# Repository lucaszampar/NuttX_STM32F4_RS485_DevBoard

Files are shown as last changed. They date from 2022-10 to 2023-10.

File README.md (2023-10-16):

# NuttX_STM32F4_RS485_DevBoard

This is the first release of a development board using the STM32F401RCT6 as the main MCU.

### Features Implemented on the Board:
- Digital I2C Temperature Sensor (TMP75)
- 256KB I2C EEPROM
- On-board RS485 Transceiver
- Two Analog Input Stages with Amplifier Buffer
- Two Analog Output Stages with Amplifier Buffer
- MicroSD Connector supporting 1 or 4-bit bus
- Four User LEDs
- Four User Buttons
- USB for DFU (Device Firmware Update) and USB device functionality, as well as powering the board
- Onboard voltage regulator from 5V to 3.3V
- SWD Pins for use as STLink (Pin header) and TC2030-IDC 6-Pin Tag-Connect Plug-of-Nails™ Connector ([More Info](https://www.tag-connect.com/product/tc2030-idc-6-pin-tag-connect-plug-of-nails-spring-pin-cable-with-legs))
- Crystal for HS 8MHz
- Crystal for RTC 32.768KHz
- STL Case available

### 3D Board Render
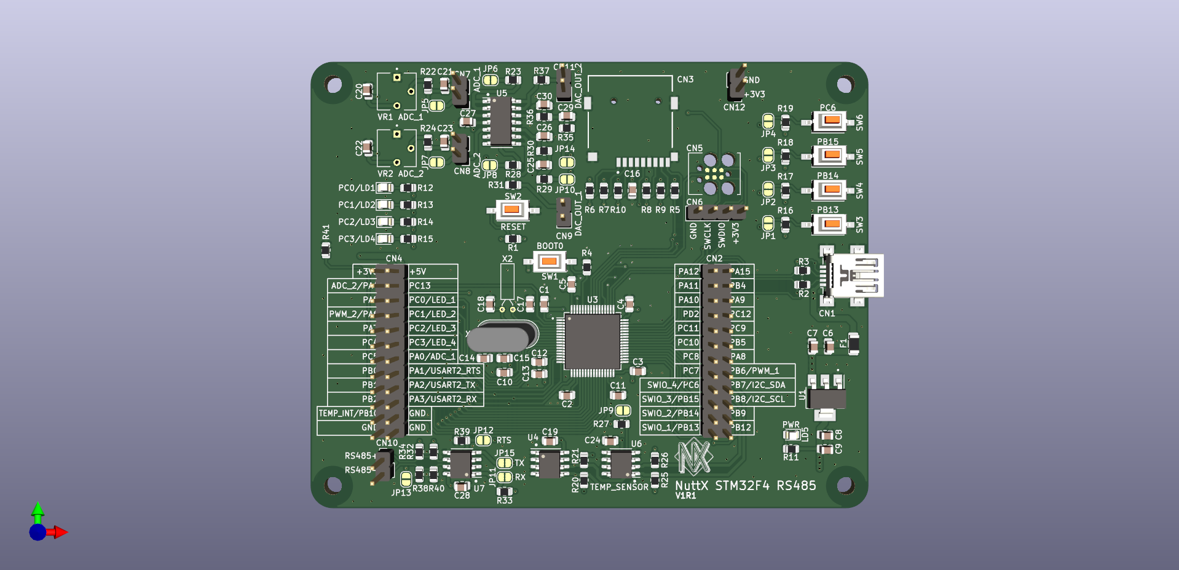
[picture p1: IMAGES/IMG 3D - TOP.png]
3D Board Render


### Case
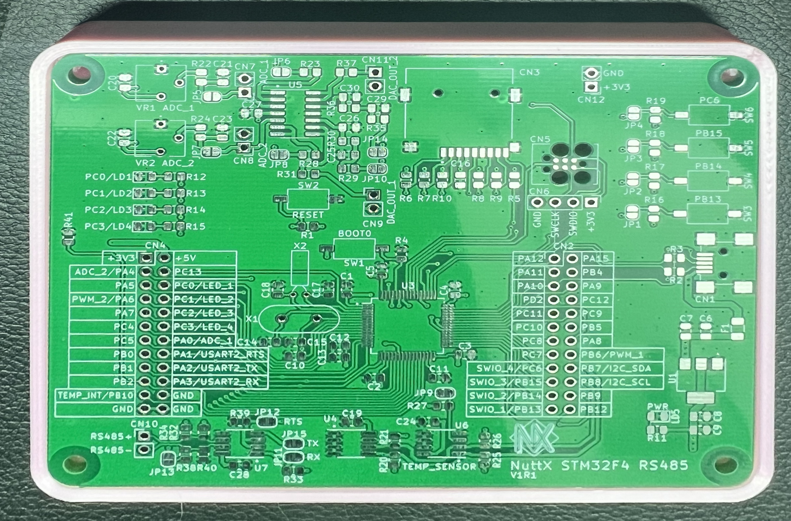
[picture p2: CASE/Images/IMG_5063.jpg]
Printed case with board


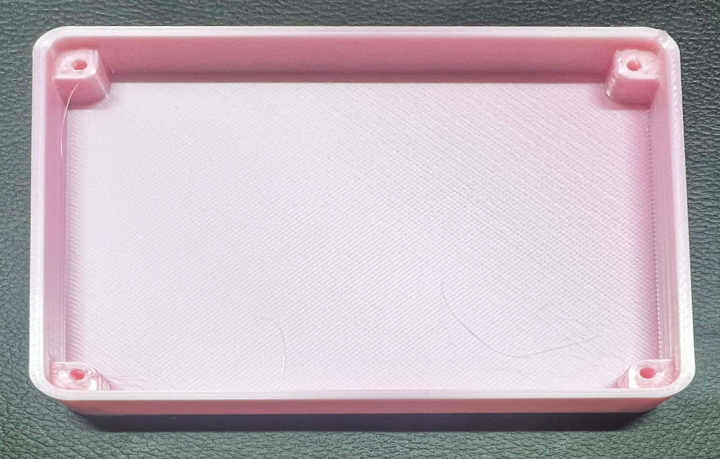
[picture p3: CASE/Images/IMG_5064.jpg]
Printed case without board


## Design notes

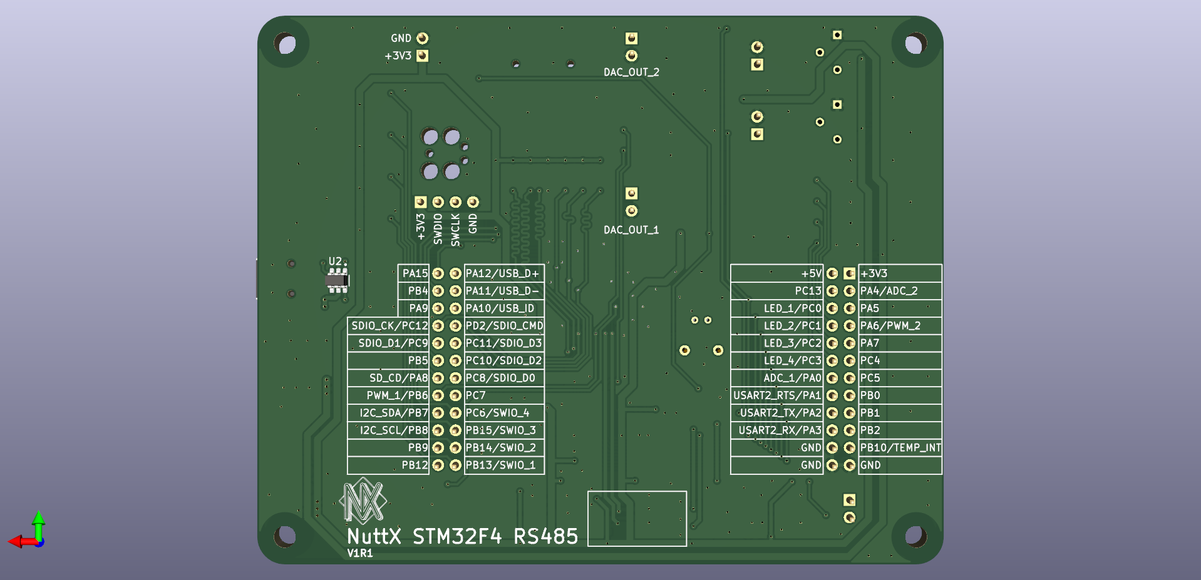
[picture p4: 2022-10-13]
IMAGES/IMG 3D - BOT.png

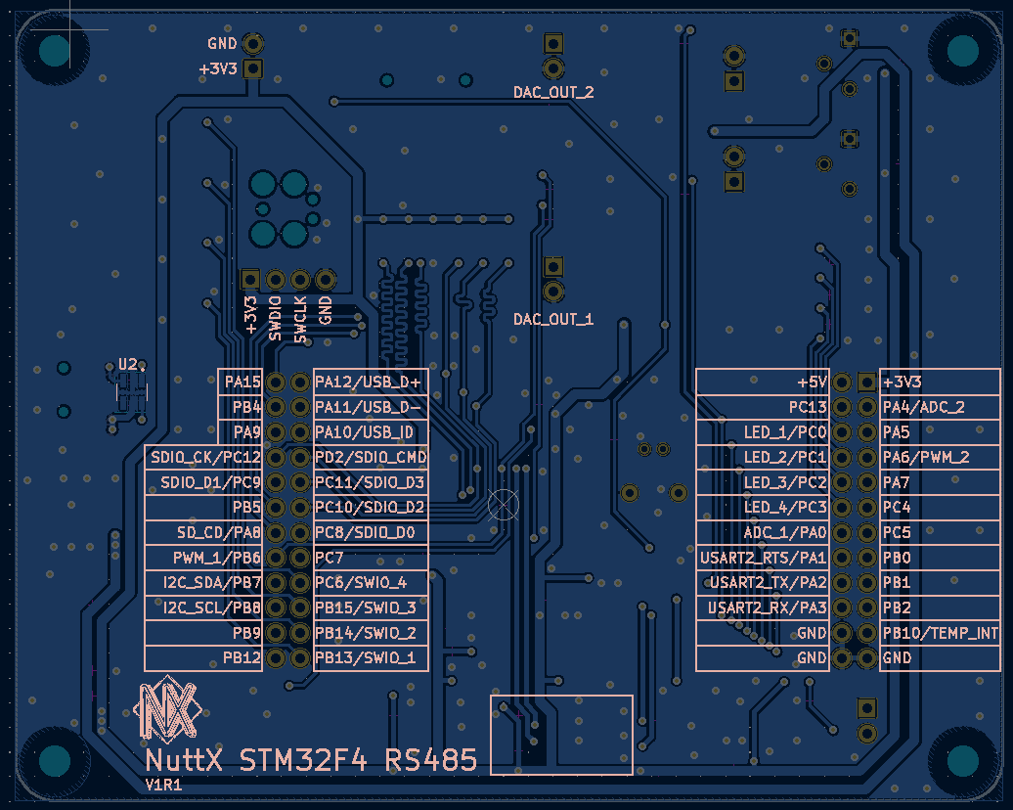
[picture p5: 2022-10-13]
IMAGES/IMG 2D - BOT.png

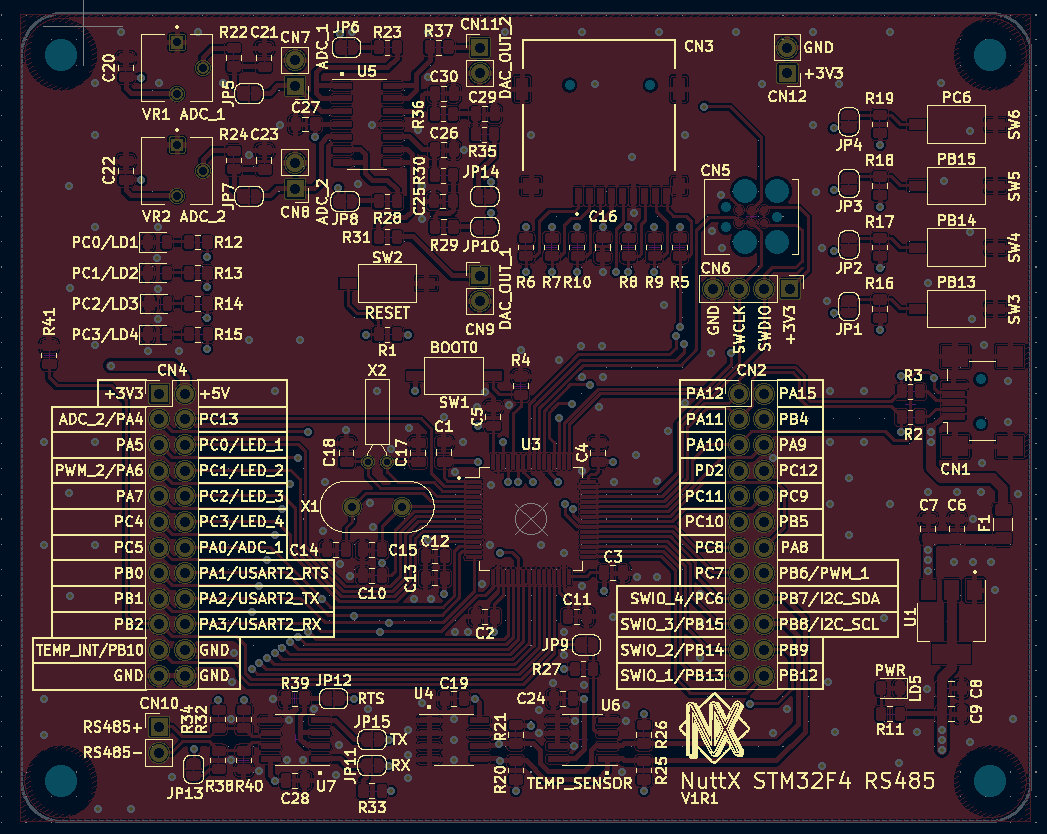
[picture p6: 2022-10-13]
IMAGES/IMG 2D - TOP.png

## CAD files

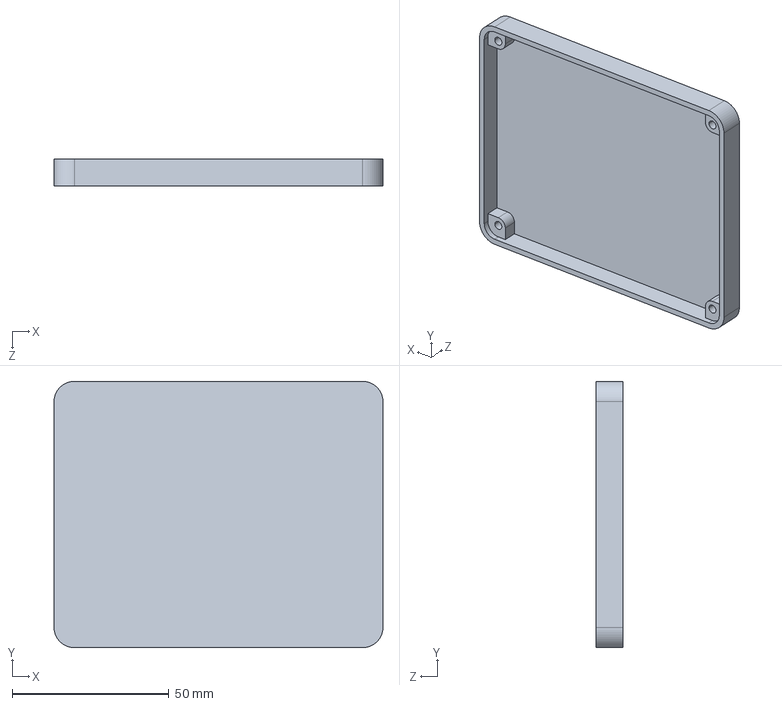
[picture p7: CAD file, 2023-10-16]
CASE/Files/Case.STEP
105.0 x 85.0 x 8.50 mm

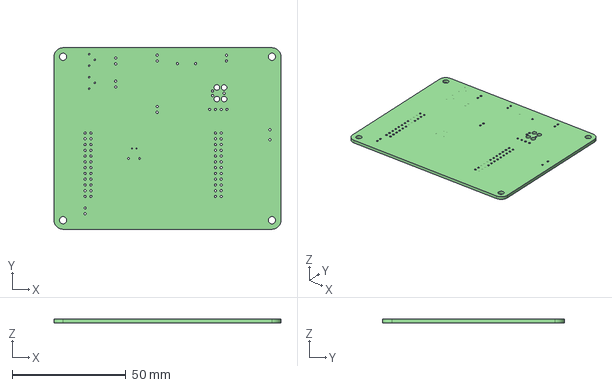
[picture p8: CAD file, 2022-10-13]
STEP/NuttX_STM32F4_RS485.step
100.0 x 80.0 x 1.60 mm

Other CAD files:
CASE/Files/Case.STL

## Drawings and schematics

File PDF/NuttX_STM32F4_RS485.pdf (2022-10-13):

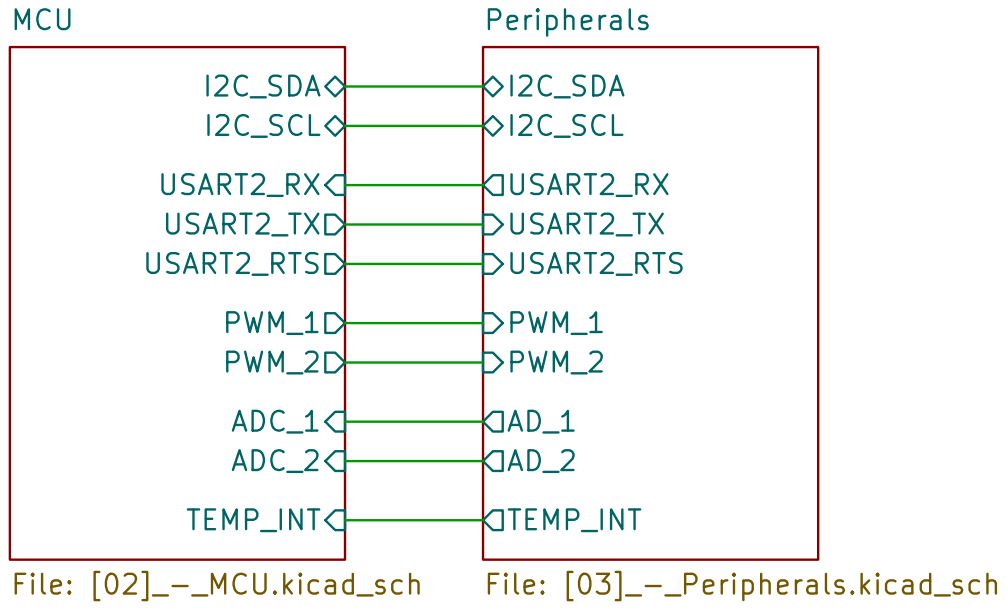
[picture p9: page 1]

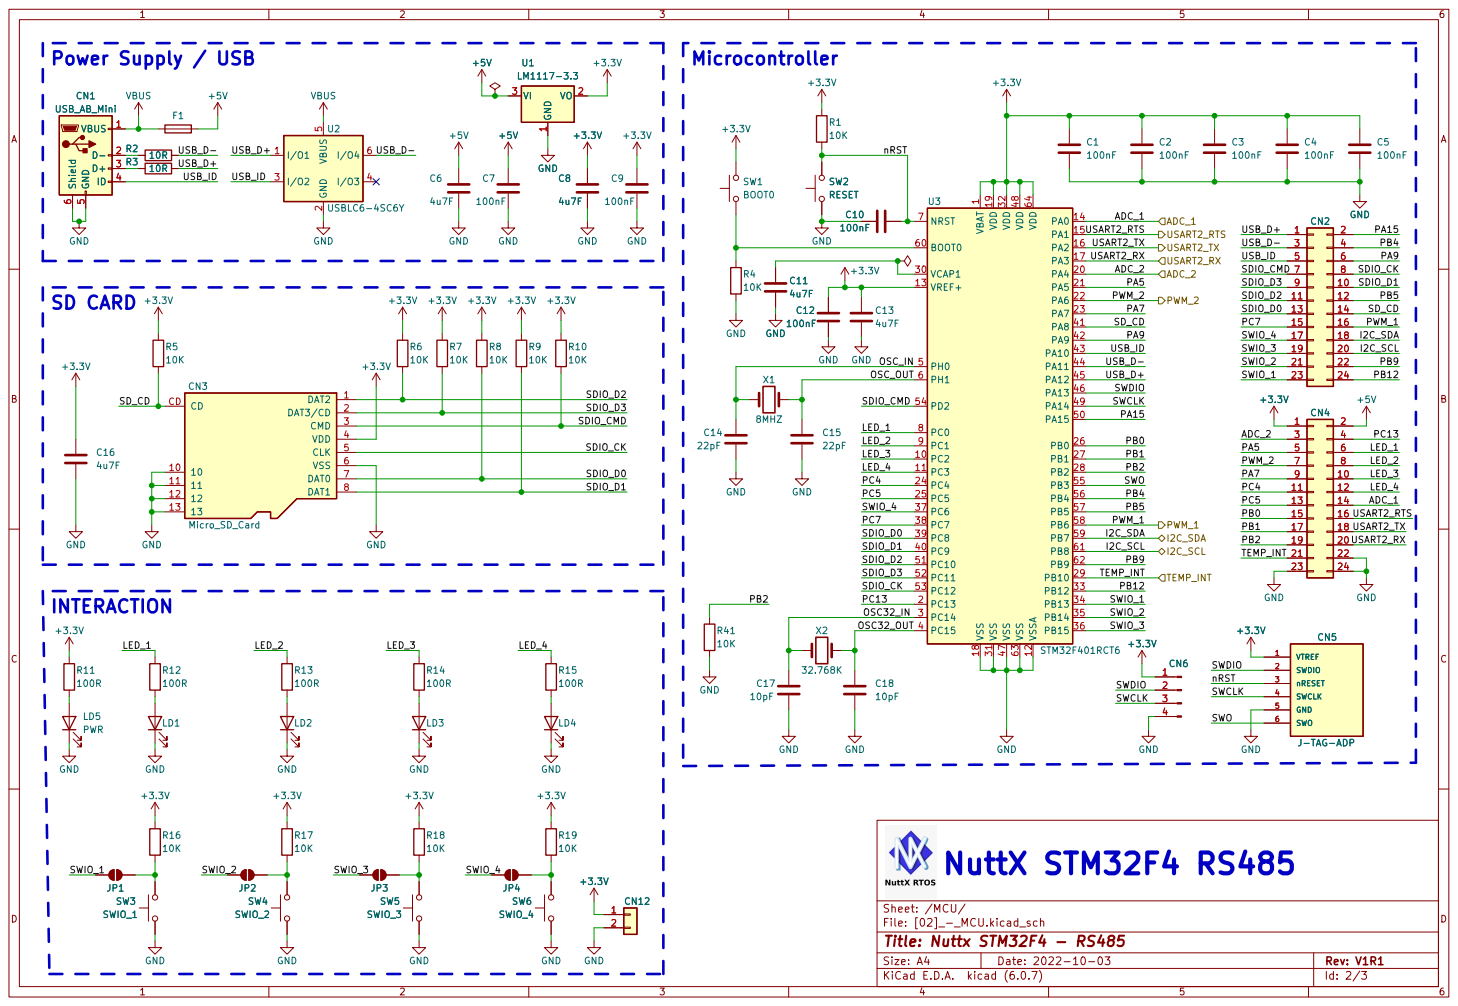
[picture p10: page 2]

1 PC2 10 PC3 11 VSSA 12 VREF+ 13 PA0 14 PA1 15 PA2 16 PA3 17 VSS 18 VDD 19 PC13 2 PA4 20 PA5 21 PA6 22 PA7 23 PC4 24 PC5 25 PB0 26 PB1 27 PB2 28 PB10 29 PC14 3 VCAP1 30 VSS 31 VDD 32 PB12 33 PB13 34 PB14 35 PB15 36 PC6 37 PC7 38 PC8 39 PC15 4 PC9 40 PA8 41 PA9 42 PA10 43 PA11 44 PA12 45 PA13 46 VSS 47 VDD 48 PA14 49 PH0 5 PA15 50 PC10 51 PC11 52 PC12 53 PD2 54 PB3 55 PB4 56 PB5 57 PB6 58 PB7 59 PH1 6 BOOT0 60 PB8 61 PB9 62 VSS 63 VDD 64 NRST 7 PC0 8 PC1 9 U3 STM32F401RCT6 GND

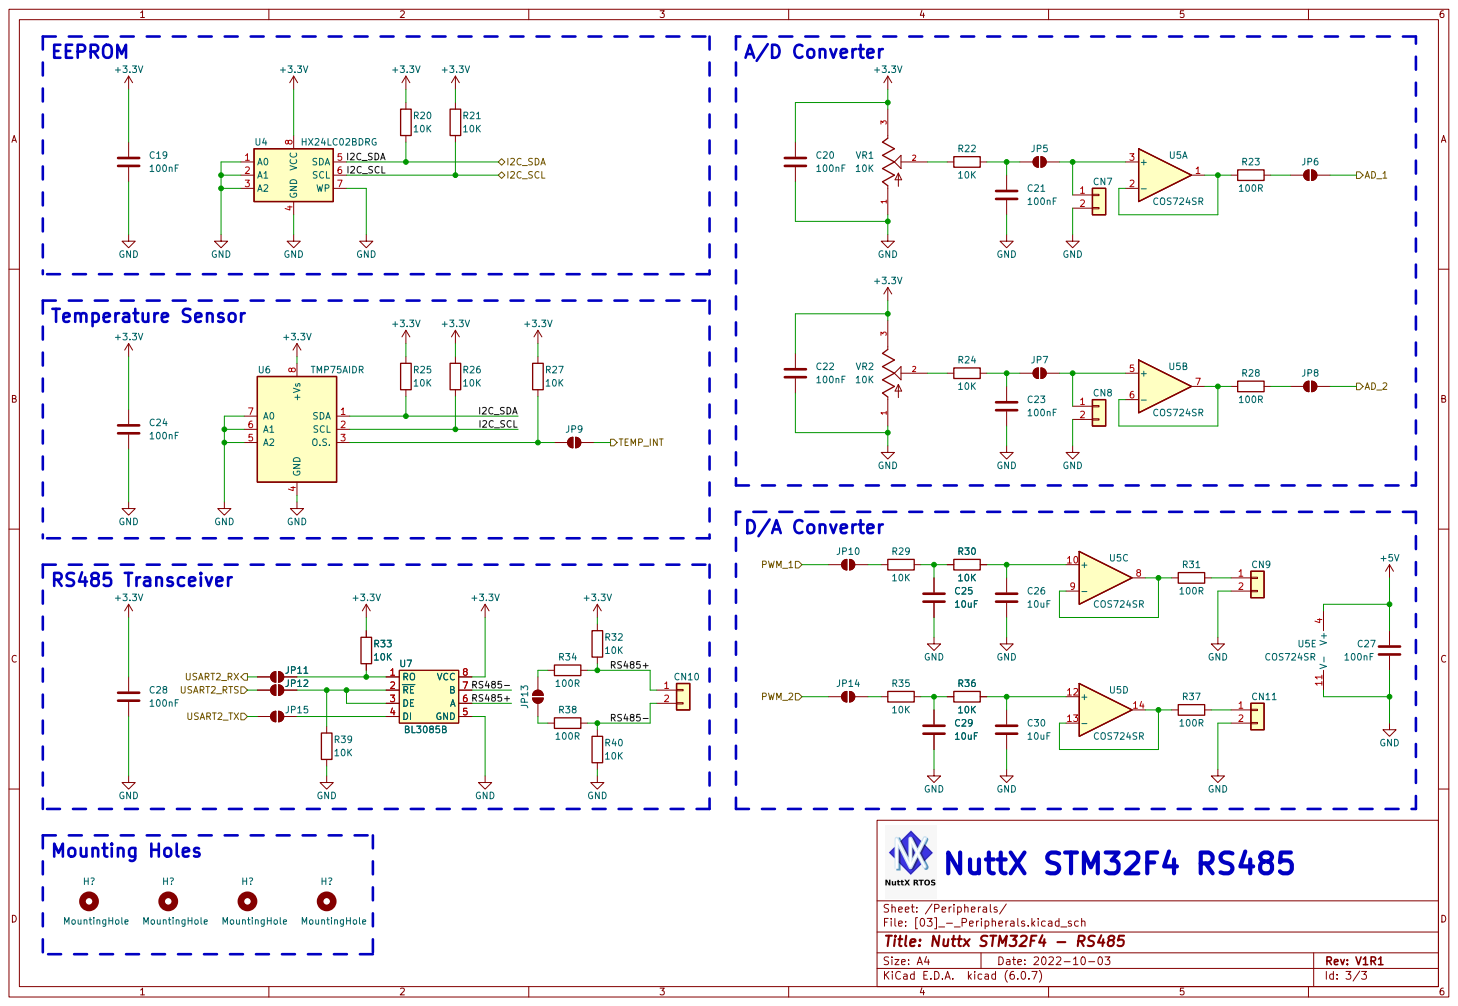
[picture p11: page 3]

4 SDA 5 SCL 6 WP 7 VCC

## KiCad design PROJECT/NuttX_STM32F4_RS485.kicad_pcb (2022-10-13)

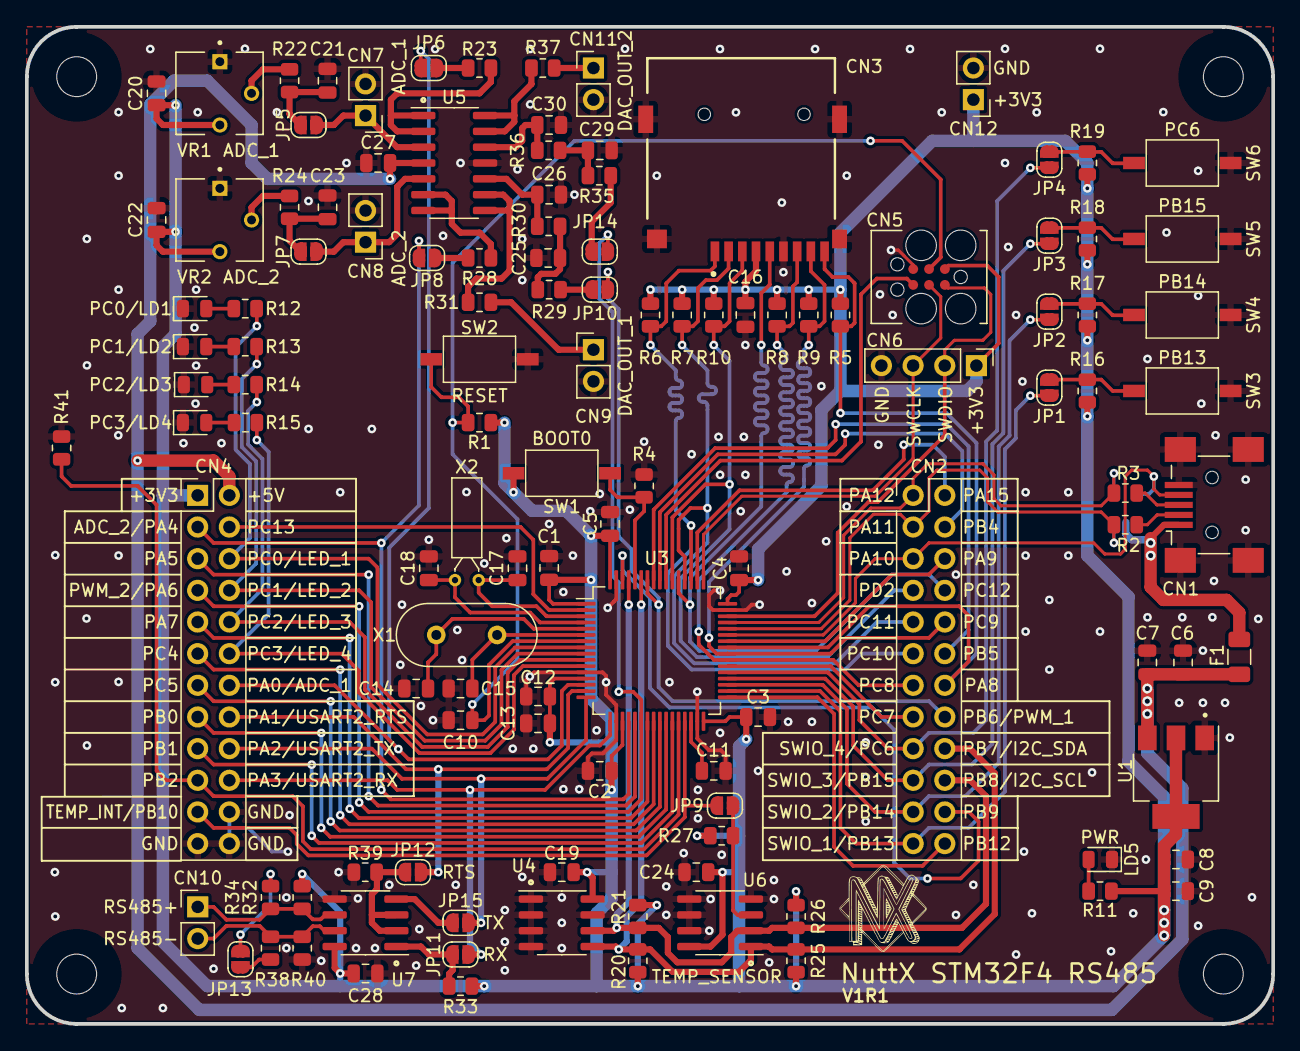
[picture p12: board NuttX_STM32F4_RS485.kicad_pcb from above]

Board: 2 copper layers, 100.0 x 80.0 mm, 125 parts (1 on the bottom side), 96 nets.

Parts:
C1, C2, C3, C4, C5, C7, C9, C10, C12, C19, C20, C21, C22, C23, C24, C27, C28: 100nF; C_0805_2012Metric
C6, C8, C11, C13, C16: 4u7F; C_0805_2012Metric
C14, C15: 22pF; C_0805_2012Metric
C17, C18: 10pF; C_0805_2012Metric
C25, C26, C29, C30: 10uF; C_0805_2012Metric
CN1: USB_AB_Mini; USB_Mini-AB_10033527-N3112MLF
CN2, CN4: Conn_02x12_Odd_Even; PinHeader_2x12_P2.54mm_Vertical
CN3: Micro_SD_Card; GCT_MEM2075-00-140-01-A
CN5: J-TAG-ADP
CN6: Conn_01x04_Male; PinHeader_1x04_P2.54mm_Vertical
CN7, CN8, CN9, CN10, CN11, CN12: Conn_01x02; PinHeader_1x02_P2.54mm_Vertical
F1: Fuse; Fuse_1206_3216Metric
H1, H2, H3, H4: MountingHole; MountingHole_3.2mm_M3
JP1, JP2, JP3, JP4, JP5, JP6, JP7, JP8, JP9, JP10, JP11, JP12, JP13, JP14, JP15: SolderJumper_2_Open; SolderJumper-2_P1.3mm_Open_RoundedPad1.0x1.5mm
LD1, LD2, LD3, LD4: BLUE; LED_0805_2012Metric
LD5: PWR; LED_0805_2012Metric
R1, R4, R5, R6, R7, R8, R9, R10, R16, R17, R18, R19, R20, R21, R22, R24, R25, R26, R27, R29, R30, R32, R33, R35, R36, R39, R40, R41: 10K; R_0805_2012Metric
R2, R3: 10R; R_0805_2012Metric
R11, R12, R13, R14, R15, R23, R28, R31, R34, R37, R38: 100R; R_0805_2012Metric
SW1: BOOT0; TSB008A2518A
SW2: RESET; TSB008A2518A
SW3: SWIO_1; TSB008A2518A
SW4: SWIO_2; TSB008A2518A
SW5: SWIO_3; TSB008A2518A
SW6: SWIO_4; TSB008A2518A
U1: LM1117-3.3; SOT-223
U2: USBLC6-4SC6Y; SOT-23-6
U3: STM32F401RCT6; LQFP-64_10x10mm_P0.5mm
U4: HX24LC02BDRG; SOIC-8_3.9x4.9mm_P1.27mm
U5: COS724SR; SOIC-14_3.9x8.7mm_P1.27mm
U6: TMP75AIDR; SOIC-8_3.9x4.9mm_P1.27mm
U7: BL3085B; SOIC-8_3.9x4.9mm_P1.27mm
VR1, VR2: 10K; TRIM_3362P-1-502
X1: 8MHZ; Crystal_HC49-U_Vertical
X2: 32.768K; Crystal_DS26_D2.0mm_L6.0mm_Horizontal

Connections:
+3.3V: C1.1, C2.1, C3.1, C4.1, C5.1, C8.1, C9.1, C12.1, C13.1, C16.1, C19.1, C20.1, C22.1, C24.1, C28.1, CN3.4 (VDD), CN4.1, CN5.1 (VTREF), CN6.1, CN12.1, R1.1, R5.1, R6.1, R7.1, R8.1, R9.1, R10.1, R11.1, R16.1, R17.1, R18.1, R19.1, R20.1, R21.1, R25.1, R26.1, R27.1, R32.1, R33.1, SW1.2, U1.2 (VO), U3.1 (VBAT), U3.13 (VREF+), U3.19 (VDD), U3.32 (VDD), U3.48 (VDD), U3.64 (VDD), U4.8 (VCC), U6.8 (+Vs), U7.8 (VCC), VR1.3, VR2.3
+5V: C6.1, C7.1, C27.1, CN4.2, F1.2, U1.3 (VI), U5.4 (V+)
/MCU/ADC_1: CN4.14, JP6.2 (B), U3.14 (PA0)
/MCU/ADC_2: CN4.3, JP8.2 (B), U3.20 (PA4)
/MCU/I2C_SCL: CN2.20, R21.2, R26.2, U3.61 (PB8), U4.6 (SCL), U6.2 (SCL)
/MCU/I2C_SDA: CN2.18, R20.2, R25.2, U3.59 (PB7), U4.5 (SDA), U6.1 (SDA)
/MCU/LED_1: CN4.6, R12.1, U3.8 (PC0)
/MCU/LED_2: CN4.8, R13.1, U3.9 (PC1)
/MCU/LED_3: CN4.10, R14.1, U3.10 (PC2)
/MCU/LED_4: CN4.12, R15.1, U3.11 (PC3)
/MCU/OSC32_IN: C17.1, U3.3 (PC14), X2.1
/MCU/OSC32_OUT: C18.1, U3.4 (PC15), X2.2
/MCU/OSC_IN: C14.1, U3.5 (PH0), X1.1
/MCU/OSC_OUT: C15.1, U3.6 (PH1), X1.2
/MCU/PA5: CN4.5, U3.21 (PA5)
/MCU/PA7: CN4.9, U3.23 (PA7)
/MCU/PA9: CN2.6, U3.42 (PA9)
/MCU/PA15: CN2.2, U3.50 (PA15)
/MCU/PB0: CN4.15, U3.26 (PB0)
/MCU/PB1: CN4.17, U3.27 (PB1)
/MCU/PB2: CN4.19, R41.1, U3.28 (PB2)
/MCU/PB4: CN2.4, U3.56 (PB4)
/MCU/PB5: CN2.12, U3.57 (PB5)
/MCU/PB9: CN2.22, U3.62 (PB9)
/MCU/PB12: CN2.24, U3.33 (PB12)
/MCU/PC4: CN4.11, U3.24 (PC4)
/MCU/PC5: CN4.13, U3.25 (PC5)
/MCU/PC7: CN2.15, U3.38 (PC7)
/MCU/PC13: CN4.4, U3.2 (PC13)
/MCU/PWM_1: CN2.16, JP10.1 (A), U3.58 (PB6)
/MCU/PWM_2: CN4.7, JP14.1 (A), U3.22 (PA6)
/MCU/SDIO_CK: CN2.8, CN3.5 (CLK), U3.53 (PC12)
/MCU/SDIO_CMD: CN2.7, CN3.3 (CMD), R10.2, U3.54 (PD2)
/MCU/SDIO_D0: CN2.13, CN3.7 (DAT0), R8.2, U3.39 (PC8)
/MCU/SDIO_D1: CN2.10, CN3.8 (DAT1), R9.2, U3.40 (PC9)
/MCU/SDIO_D2: CN2.11, CN3.1 (DAT2), R6.2, U3.51 (PC10)
/MCU/SDIO_D3: CN2.9, CN3.2 (DAT3/CD), R7.2, U3.52 (PC11)
/MCU/SD_CD: CN2.14, CN3.CD, R5.2, U3.41 (PA8)
/MCU/SWCLK: CN5.4 (SWCLK), CN6.3, U3.49 (PA14)
/MCU/SWDIO: CN5.2 (SWDIO), CN6.2, U3.46 (PA13)
/MCU/SWIO_1: CN2.23, JP1.1 (A), U3.34 (PB13)
/MCU/SWIO_2: CN2.21, JP2.1 (A), U3.35 (PB14)
/MCU/SWIO_3: CN2.19, JP3.1 (A), U3.36 (PB15)
/MCU/SWIO_4: CN2.17, JP4.1 (A), U3.37 (PC6)
/MCU/SWO: CN5.6 (SWO), U3.55 (PB3)
/MCU/TEMP_INT: CN4.21, JP9.2 (B), U3.29 (PB10)
/MCU/USART2_RTS: CN4.16, JP12.1 (A), U3.15 (PA1)
/MCU/USART2_RX: CN4.20, JP11.1 (A), U3.17 (PA3)
/MCU/USART2_TX: CN4.18, JP15.1 (A), U3.16 (PA2)
/MCU/USB_D+: CN2.1, R3.2, U2.1 (I/O1), U3.45 (PA12)
/MCU/USB_D-: CN2.3, R2.2, U2.6 (I/O4), U3.44 (PA11)
/MCU/USB_ID: CN1.4 (ID), CN2.5, U2.3 (I/O2), U3.43 (PA10)
/MCU/nRST: C10.2, CN5.3 (nRESET), R1.2, SW2.2, U3.7 (NRST)
/Periféricos/RS485+: CN10.1, R32.2, R34.1, U7.6 (A)
/Periféricos/RS485-: CN10.2, R38.1, R40.1, U7.7 (B)
GND: C1.2, C2.2, C3.2, C4.2, C5.2, C6.2, C7.2, C8.2, C9.2, C10.1, C11.2, C12.2, C13.2, C14.2, C15.2, C16.2, C17.2, C18.2, C19.2, C20.2, C21.2, C22.2, C23.2, C24.2, C25.2, C26.2, C27.2, C28.2, C29.2, C30.2, CN1.5 (GND), CN1.6 (Shield), CN3.6 (VSS), CN3.10, CN3.11, CN3.12, CN3.13, CN4.22, CN4.23, CN4.24, CN5.5 (GND), CN6.4, CN7.2, CN8.2, CN9.2, CN11.2, CN12.2, LD1.1 (K), LD2.1 (K), LD3.1 (K), LD4.1 (K), LD5.1 (K), R4.2, R39.2, R40.2, R41.2, SW2.1, SW3.1, SW4.1, SW5.1, SW6.1, U1.1 (GND), U2.2 (GND), U3.12 (VSSA), U3.18 (VSS), U3.31 (VSS), U3.47 (VSS), U3.63 (VSS), U4.1 (A0), U4.2 (A1), U4.3 (A2), U4.4 (GND), U4.7 (WP), U5.11 (V-), U6.4 (GND), U6.5 (A2), U6.6 (A1), U6.7 (A0), U7.5 (GND), VR1.1, VR2.1
unnamed: C11.1, U3.30 (VCAP1)
unnamed: C21.1, JP5.1 (A), R22.2
unnamed: C23.1, JP7.1 (A), R24.2
unnamed: C25.1, R29.2, R30.1
unnamed: C26.1, R30.2, U5.10 (+)
unnamed: C29.1, R35.2, R36.1
unnamed: C30.1, R36.2, U5.12 (+)
unnamed: CN1.2 (D-), R2.1
unnamed: CN1.3 (D+), R3.1
unnamed: CN7.1, JP5.2 (B), U5.3 (+)
unnamed: CN8.1, JP7.2 (B), U5.5 (+)
unnamed: CN9.1, R31.2
unnamed: CN11.1, R37.2
unnamed: JP1.2 (B), R16.2, SW3.2
unnamed: JP2.2 (B), R17.2, SW4.2
unnamed: JP3.2 (B), R18.2, SW5.2
unnamed: JP4.2 (B), R19.2, SW6.2
unnamed: JP6.1 (A), R23.2
unnamed: JP8.1 (A), R28.2
unnamed: JP9.1 (A), R27.2, U6.3 (O.S.)
unnamed: JP10.2 (B), R29.1
unnamed: JP11.2 (B), R33.2, U7.1 (RO)
unnamed: JP12.2 (B), R39.1, U7.2 (~RE), U7.3 (DE)
unnamed: JP13.1 (A), R38.2
unnamed: JP13.2 (B), R34.2
unnamed: JP14.2 (B), R35.1
unnamed: JP15.2 (B), U7.4 (DI)
unnamed: LD1.2 (A), R12.2
unnamed: LD2.2 (A), R13.2
unnamed: LD3.2 (A), R14.2
unnamed: LD4.2 (A), R15.2
unnamed: LD5.2 (A), R11.2
unnamed: R4.1, SW1.1, U3.60 (BOOT0)
unnamed: R22.1, VR1.2
unnamed: R23.1, U5.1, U5.2 (-)
unnamed: R24.1, VR2.2
unnamed: R28.1, U5.6 (-), U5.7
unnamed: R31.1, U5.8, U5.9 (-)
unnamed: R37.1, U5.13 (-), U5.14
VBUS: CN1.1 (VBUS), F1.1, U2.5 (VBUS)
